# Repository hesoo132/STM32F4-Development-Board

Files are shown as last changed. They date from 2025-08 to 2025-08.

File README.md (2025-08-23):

## 📑 Table of Contents
1. [Power](#1-power-전원부)  
2. [Pin Port](#2-pin-port-핀-포트)  
3. [USB](#3-usb)  
4. [Crystal](#4-crystal-크리스탈-오실레이터)  
5. [MCU](#5-mcu-마이크로컨트롤러-유닛)  
6. [Conclusion](#6-결론)  

---

## 1. Power
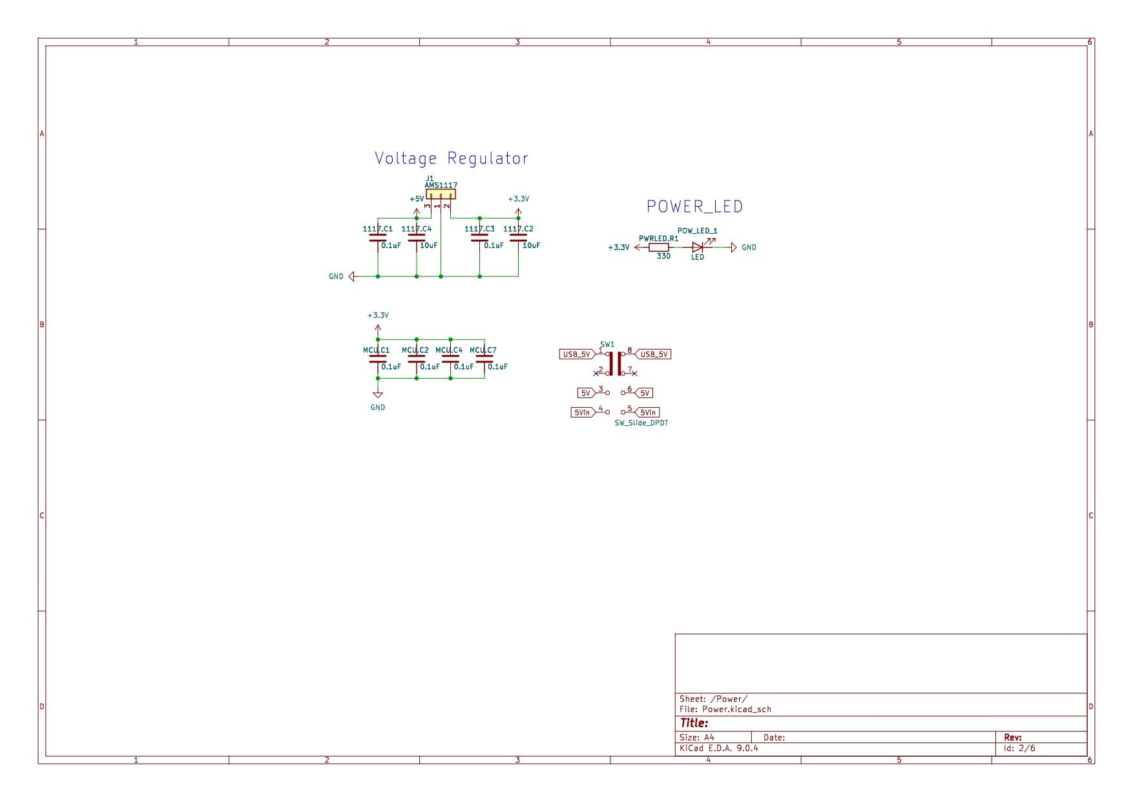
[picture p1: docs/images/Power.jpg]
Power Schematic


- **Function**: Converts external 5V input into a regulated 3.3V supply for the MCU and peripherals.  
- **Components**:  
  - AMS1117 regulator (J1)  
  - Power LED (POW_LED_1) with resistor (330Ω)  
  - Slide switch (SW_Slide_DPDT, SW1) for power control  
  - Decoupling capacitors (0.1µF, 10µF) for stability  

---

## 2. Pin Port
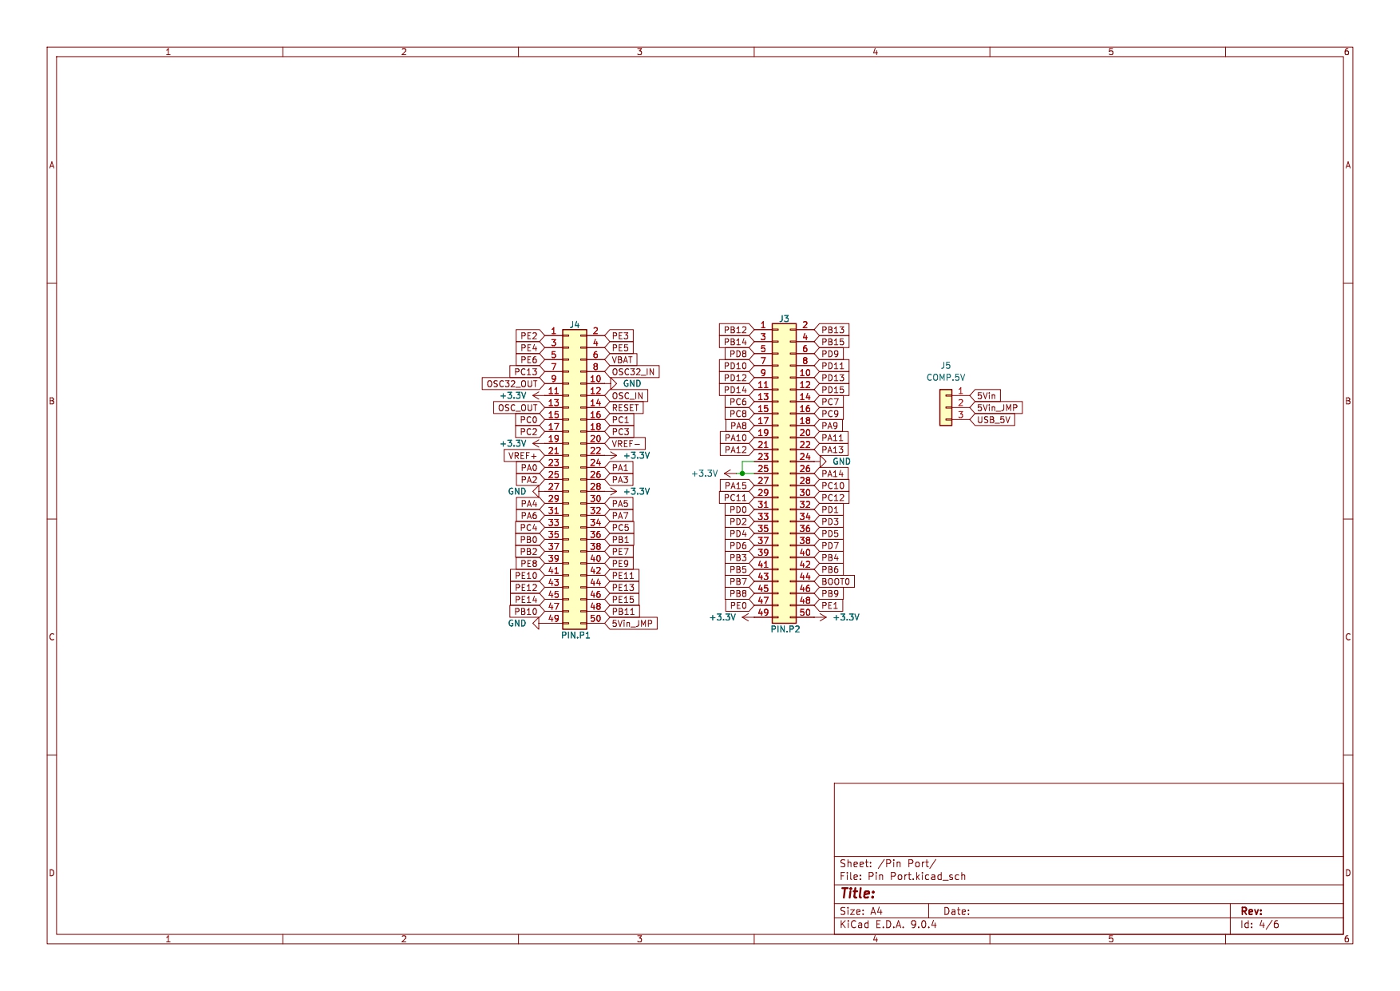
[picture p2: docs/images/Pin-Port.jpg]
Pin Port Schematic


- **Function**: Exposes STM32F407VETx GPIOs through external connectors (J3, J4, J5).  
- **Available Pins**:  
  - GPIO groups: PA, PB, PC, PD, PE  
  - Clock pins: OSC_IN, OSC_OUT, OSC32_IN, OSC32_OUT  
  - Reset and Boot pins  
- **Purpose**: Enables flexible interfacing with sensors, actuators, or other controllers.  

---

## 3. USB
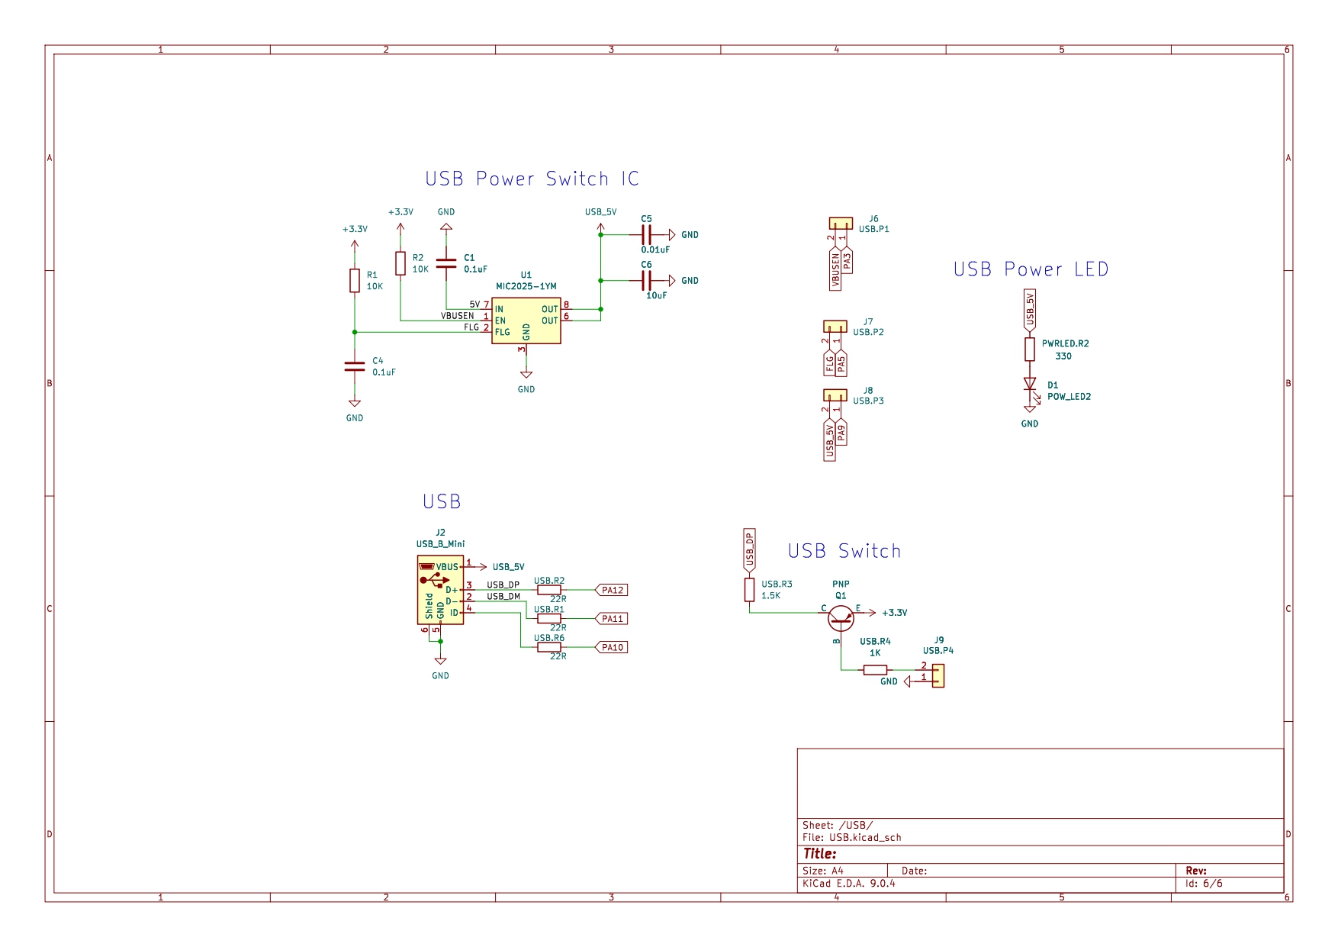
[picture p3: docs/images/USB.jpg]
USB Schematic


- **Function**: Provides USB communication via a Mini-B connector (J2).  
- **Components**:  
  - MIC2025-1YM USB power switch (U1)  
  - Data lines: USB_DP, USB_DM  
  - Protection & series resistors (22Ω)  
  - Power LED (POW_LED2)  
- **Notes**: Supports regulated USB 5V input, current limiting, and device connectivity.  

---

## 4. Crystal
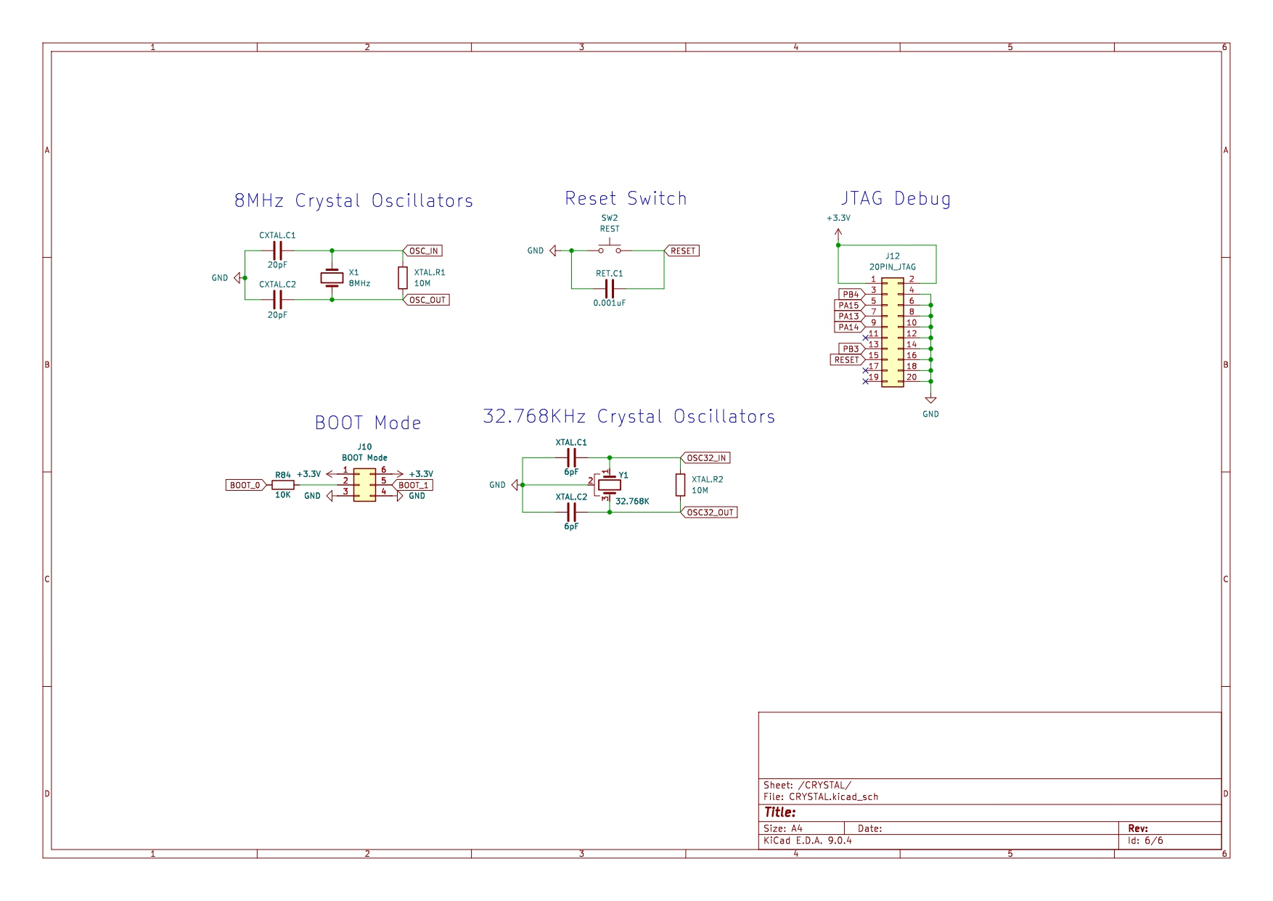
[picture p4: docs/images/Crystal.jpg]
Crystal Schematic


- **Function**: Provides accurate clock sources for the MCU.  
- **Components**:  
  - 8MHz main oscillator (X1) with load capacitors (20pF)  
  - 32.768kHz RTC crystal (Y1) with 6pF capacitors  
  - BOOT Mode selector (J10)  
  - Reset switch (SW2)  
  - 20-pin JTAG/SWD connector (J12) for debugging  

---

## 5. MCU
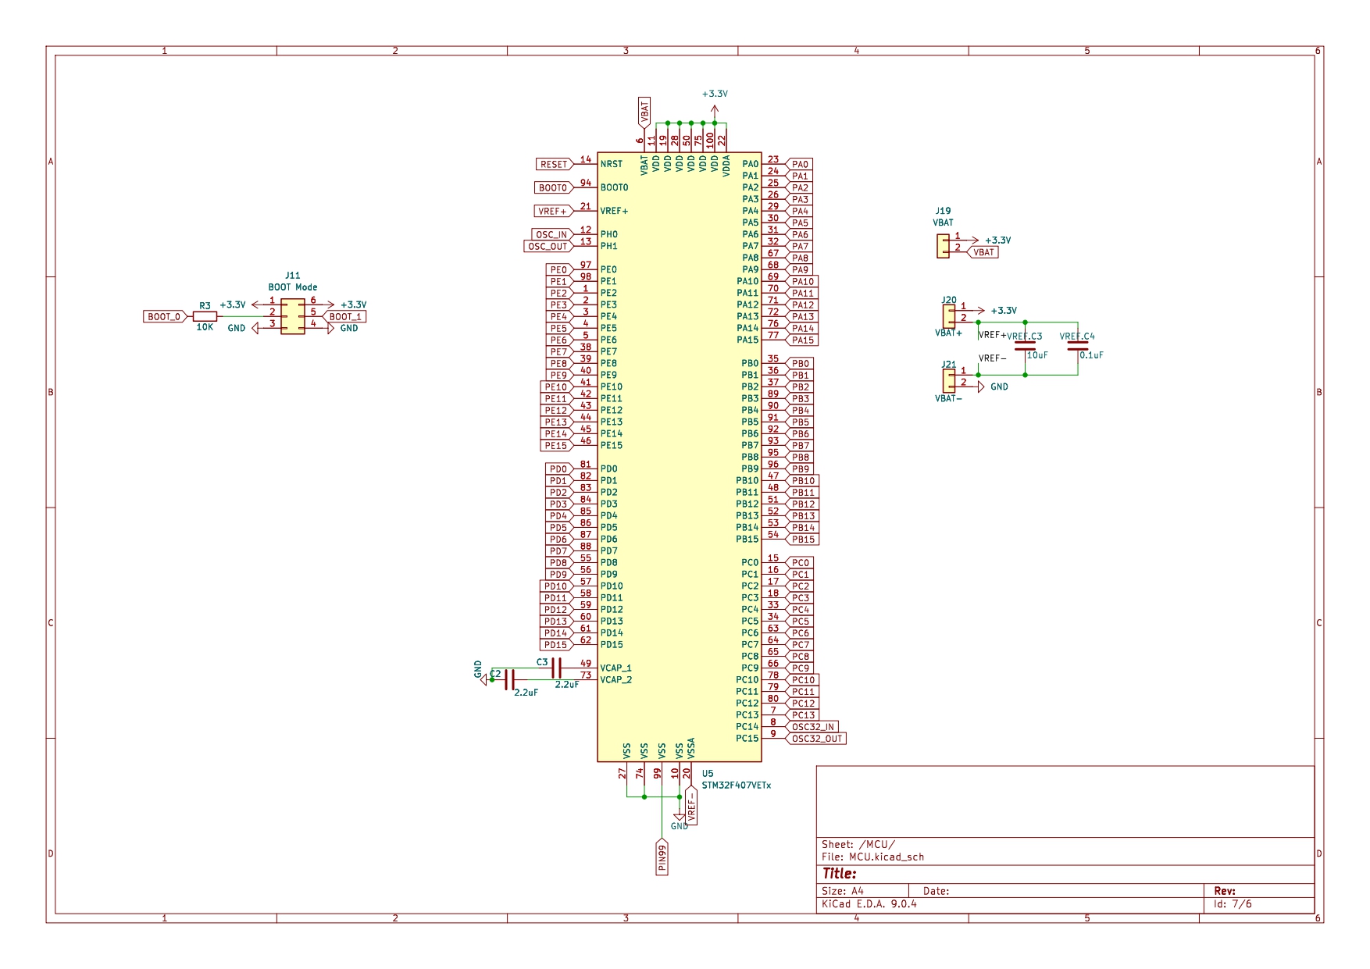
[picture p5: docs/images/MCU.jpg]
MCU Schematic

- **Model**: STM32F407VETx (ARM Cortex-M4)  
- **Function**: Central controller handling all peripherals and system logic.  
- **Connections**:  
  - VCAP capacitors (2.2µF each)  
  - Power pins (3.3V, GND)  
  - BOOT mode jumper (J11)  
  - VBAT connections (J19, J20, J21)  
  - GPIOs (Ports A–E) routed to external headers  
- **Features**:  
  - High-performance MCU core for DSP and control  
  - Rich GPIO set for flexible interfacing  
  - Supports external oscillators and USB  

---

## 6. Conclusion

The **STM32F4Core board** is a versatile core board designed around the STM32F407VETx MCU.  

- **Power Management**: 5V input regulated to 3.3V, with onboard monitoring LEDs and USB power switch.  
- **Expansion**: GPIO-rich design with external pin headers (J3, J4, J5).  
- **USB Support**: Integrated Mini-B port with MIC2025-based power management.  
- **Clock Accuracy**: Dual-crystal design (8MHz + 32.768kHz) ensures reliable MCU timing.  
- **Debugging**: JTAG/SWD interface available for firmware development.  

This makes the board suitable for **embedded system prototyping, robotics, sensor interfacing, and educational use cases** requiring a stable STM32F4 platform.  

---

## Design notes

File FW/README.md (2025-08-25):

# 🔧 STM32F4 Development Board Firmware

## 🔎 Overview
This firmware is designed for the **STM32F407ZET6 Development Board**.  
It provides examples for GPIO, UART, LCD, Timer, PWM, ADC, DAC, I2C and peripheral control.  
The code demonstrates **interrupt-based handling, polling-based logic, and peripheral drivers** using STM32 HAL.

---

## ⚙️ Features

### 1) LED Control
- **B1** → Interrupt-based toggle of LD1  
- **B2** → Polling: Turn ON LEDs  
- **B3** → Polling: Turn OFF LEDs  
- **B4** → Interrupt: Sync LD2 with LD1 (using flag `led_turned_on`)  

👉 Implemented via:
- `HAL_GPIO_EXTI_Callback()` → Handle external interrupts for B1/B4  
- `while(1)` loop polling with `HAL_GPIO_ReadPin()` for B2/B3  

---

### 2) UART – LED Control
- UART1 interrupt receive enabled (`HAL_UART_Receive_IT`)  
- Case 1: Characters `A–C` turn ON LD1, `D–F` turn OFF LD1  
- Case 2: Strings `"LED ON"` and `"LED OFF"` toggle LD2  

👉 Implemented via:
- `HAL_UART_RxCpltCallback()` with buffer and string comparison (`strncmp`)  

---

### 3) UART – LCD Display
- Input characters displayed on **20×4 LCD** via UART interrupt  
- `"Clear"` command clears LCD and resets cursor row  
- Auto line feed with row increment  
- Uses `lcd_Init(4,20), lcd_setCursor(), lcd_string()`  

---

### 4) Timer Control (Reaction Test)
- LD1 (PG13) starts ON, LD2 (PG14) OFF  
- LD1 turns OFF randomly after 1–5 sec (using `rand()`)  
- Then LD2 turns ON randomly after 1–5 sec  
- LCD shows **“R U Ready…?”** and then reaction speed time  
- Button PA0 → Stop timer and freeze reaction time  

👉 Implemented via:
- `HAL_TIM_PeriodElapsedCallback(TIM7)` for random timing  
- `HAL_GPIO_EXTI_Callback()` for stop/resume with button  

---

### 5) Timer Control 2 – Dual LED Toggle
- TIM7 → Toggle LD1 every 1 sec  
- TIM6 → Toggle LD2 every 2 sec  

👉 Implemented via:
- Two base timers with independent callbacks in `HAL_TIM_PeriodElapsedCallback()`  

---

### 6) PWM Control
- **Button 1** → PWM 100Hz  
- **Button 2** → PWM 400Hz  
- **Button 3** → Duty cycle 25%  
- **Button 4** → Duty cycle 75%  

👉 Implemented via:
- TIM2 PWM configuration, updating `PSC`, `ARR`, `CCR1`  
- Flags set by EXTI interrupts (B1–B4)  

---

### 7) PWM Applications
- **SG90 Servo Motor (TIM4_CH2)**  
- **Buzzer (TIM3_CH1)** → 500Hz–1kHz tone  
- **DC Motor (TIM2_CH1/CH2)** → Forward/reverse rotation with duty change  

👉 Real-time PWM frequency adjustment via `PSC` or `ARR` update.  

---

### 8) DAC
- **DAC1 (PA4)** outputs analog voltage (0–3.3V, 12-bit)  
- Example: Constant 1.6V, triangle wave, sine wave with TIM7 interrupt  

👉 Implemented via:
- `HAL_DAC_Start()`  
- `HAL_DAC_SetValue()`  

---

### 9) I2C – EEPROM + LCD
- I2C1 used to read/write external EEPROM (0xA0)  
- Write 10 bytes → Read back & display on LCD  
- Must use `I2C_MEMADD_SIZE_16BIT` for addressing  

👉 Implemented via:
- `HAL_I2C_Mem_Write()` and `HAL_I2C_Mem_Read()`  
- Display results with `lcd_setCurStr()`

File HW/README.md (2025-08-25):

# STM32F4Core Hardware Design

## 🔎 Overview
The **STM32F4Core Board** is a custom core platform built on the **STM32F407VETx** MCU.  
It provides stable power regulation, rich GPIO breakouts, USB connectivity, accurate system/RTC clocks, and full JTAG/SWD debug support for embedded development.

---

## 📸 PCB Overview
| Top View | Bottom View |
|---|---|
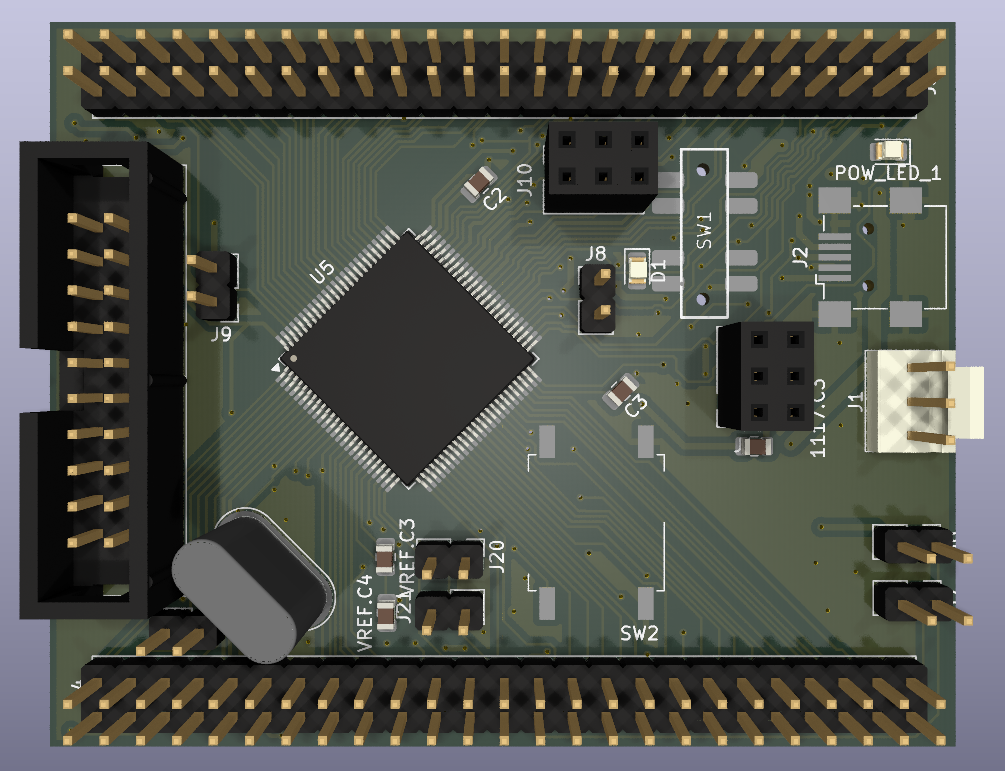
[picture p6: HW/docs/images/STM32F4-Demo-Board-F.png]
Top
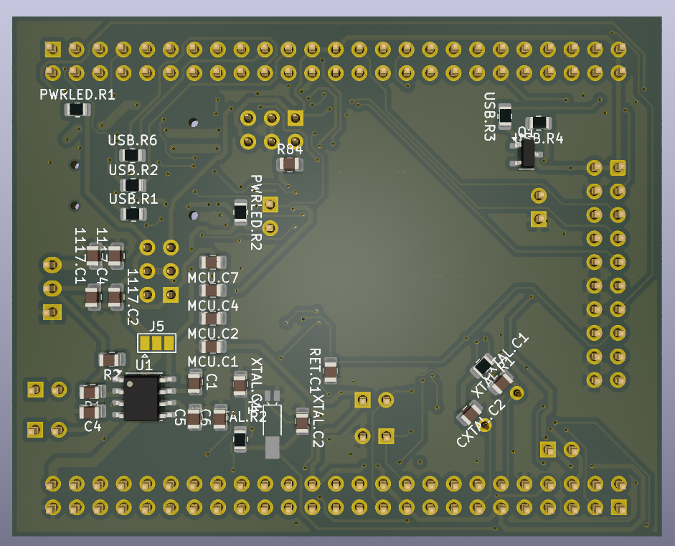
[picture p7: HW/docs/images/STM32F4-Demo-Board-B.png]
Bottom
|  |  |

---

## 📑 Design Resources
- **Schematics**: [STM32F4Core.pdf](STM32F4-Demo-Board.pdf) (6-page schematic for quick view)  
- **EDA Tool**: KiCad (v7)  

---

## 🔧 Key Hardware Notes
- **MCU**: STM32F407VETx (ARM Cortex-M4, 168 MHz, FPU)  
- **Power**: 5 V input → AMS1117 regulator → 3.3 V rail, with on/off slide switch & LED indicator  
- **Clocks**: 8 MHz main crystal + 32.768 kHz RTC crystal  
- **USB**: USB Mini-B connector with **MIC2025-1YM** power switch  
- **GPIO**: PA–PE group pins exposed to headers (J3/J4/J5)  
- **Debug**: 20-pin JTAG header (J12), boot-mode jumper (J11), reset switch (SW2)  

---

## 🧩 Schematic Highlights

### 1) Power
Power  
- **Regulator**: AMS1117 (5 V → 3.3 V)  
- **Indicators**: Power LED (POW_LED_1)  
- **Switch**: Slide switch (SW_Slide_DPDT) for on/off control  

### 2) Pin Ports
Ports  
- **Headers**: J3, J4, J5  
- **Signals**: MCU GPIO (PA/PB/PC/PD/PE), reset, oscillator pins  
- **Use**: Sensor/actuator connections, external module interfacing  

### 3) USB
USB  
- **Connector**: USB Mini-B (J2)  
- **Power Switch**: MIC2025-1YM, with EN/FLG signals to MCU  
- **Signals**: Provides regulated **USB_5V** rail (with current-limit & flag)  
- **Note**: **Power-only design** — no D+/D− data lines connected to MCU. 

### 4) Clocks & Debug
Clocks  
- **Crystals**: 8 MHz (system), 32.768 kHz (RTC)  
- **Reset**: Push switch (SW2)  
- **Debug**: 20-pin JTAG header (J12)  

### 5) MCU
MCU  
- **Chip**: STM32F407VETx  
- **Support**: VCAP capacitors, bypass network, boot-mode jumper (J11)  
- **Role**: Main controller for application logic & peripherals  

---

## ✅ Progress
- [x] Schematics completed (6 pages)  
- [x] PCB prototype fabricated (Rev. A)  
- [x] Power rails validated (5 V → 3.3 V)  
- [x] JTAG/SWD debug verified   
- [x] Full GPIO validation in progress

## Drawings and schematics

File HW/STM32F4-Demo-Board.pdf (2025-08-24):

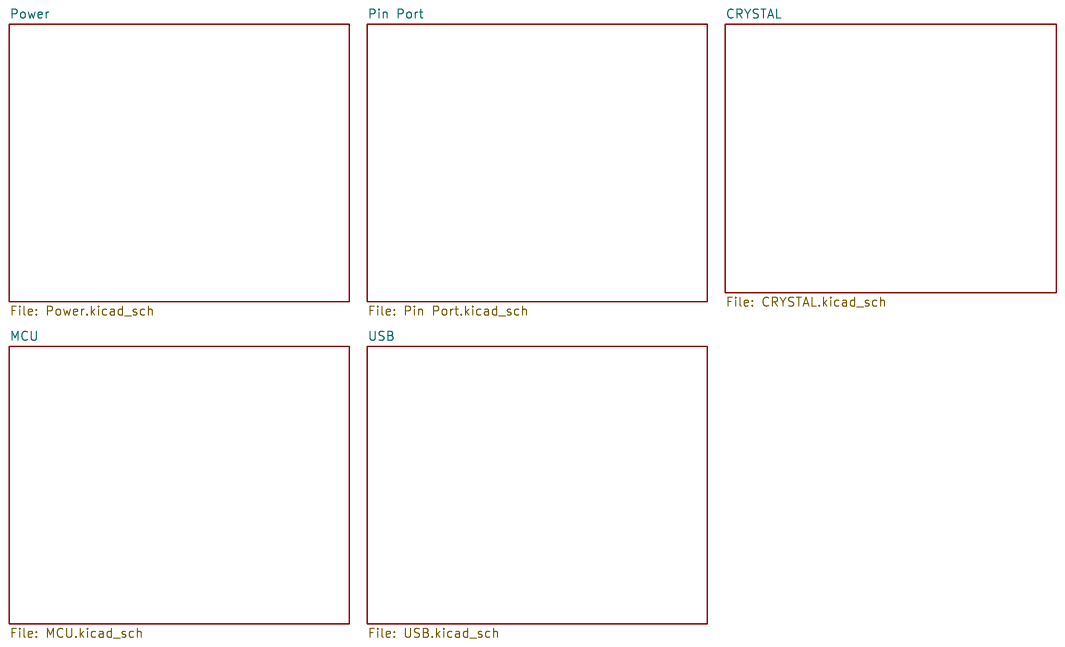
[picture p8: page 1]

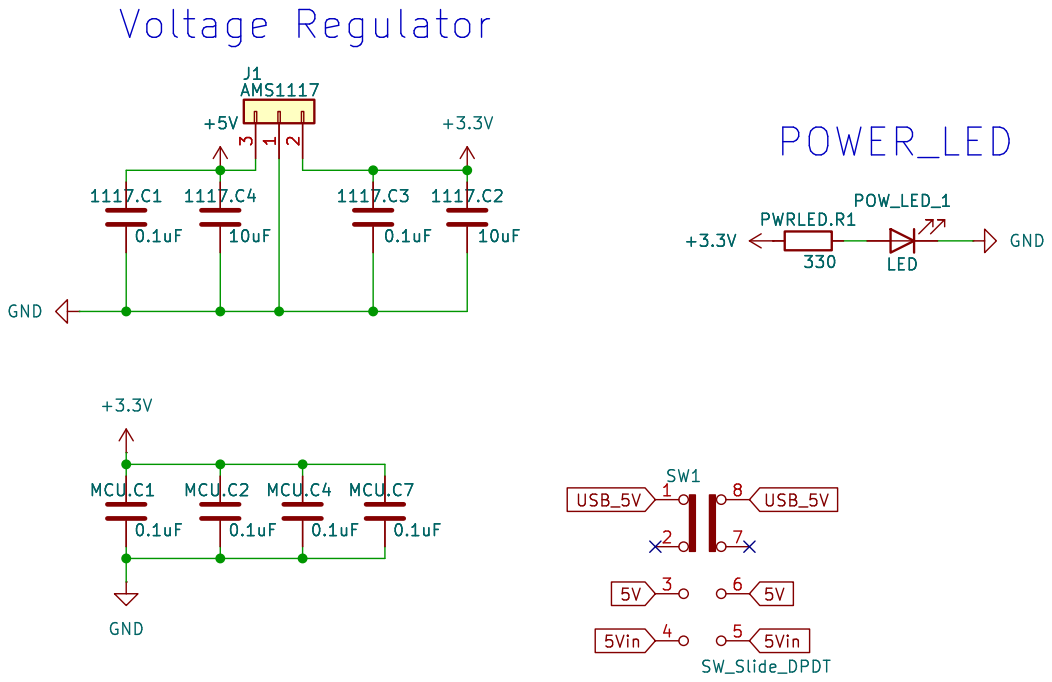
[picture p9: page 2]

Id: 2/6 Title: File: Power.kicad_sch Sheet: /Power/

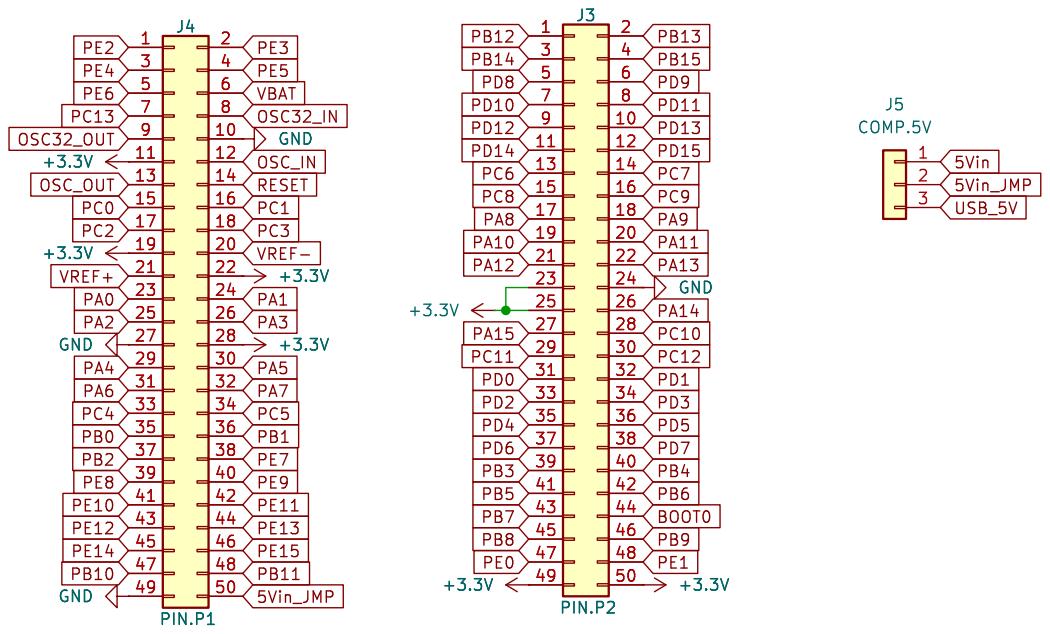
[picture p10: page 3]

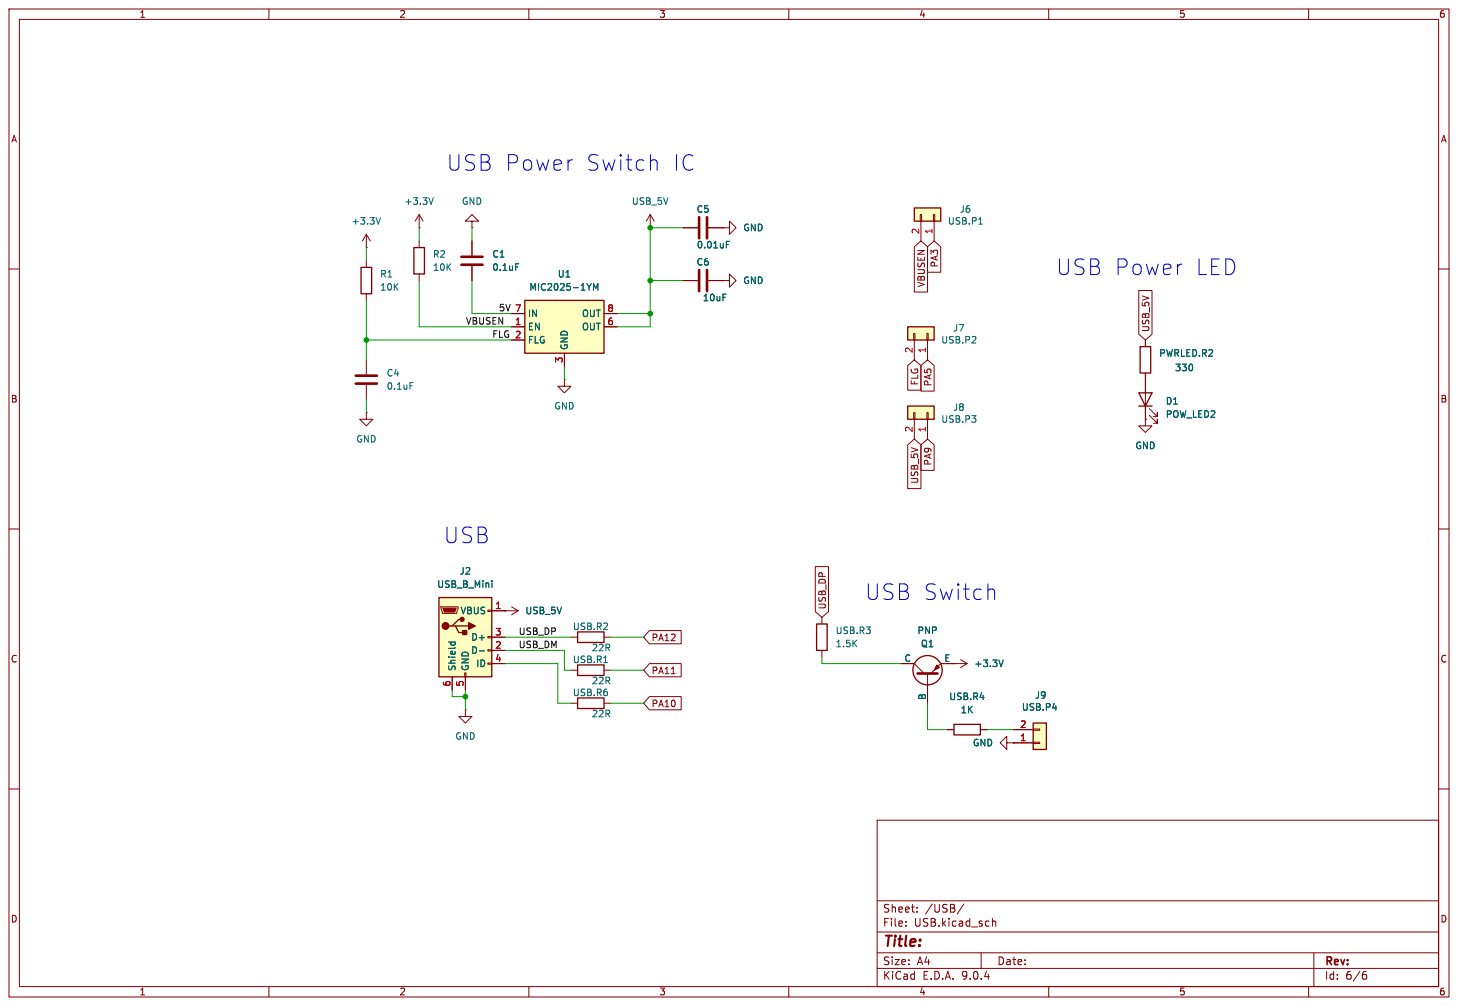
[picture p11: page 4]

Id: 6/6 Title: File: USB.kicad_sch Sheet: /USB/ USB.R3

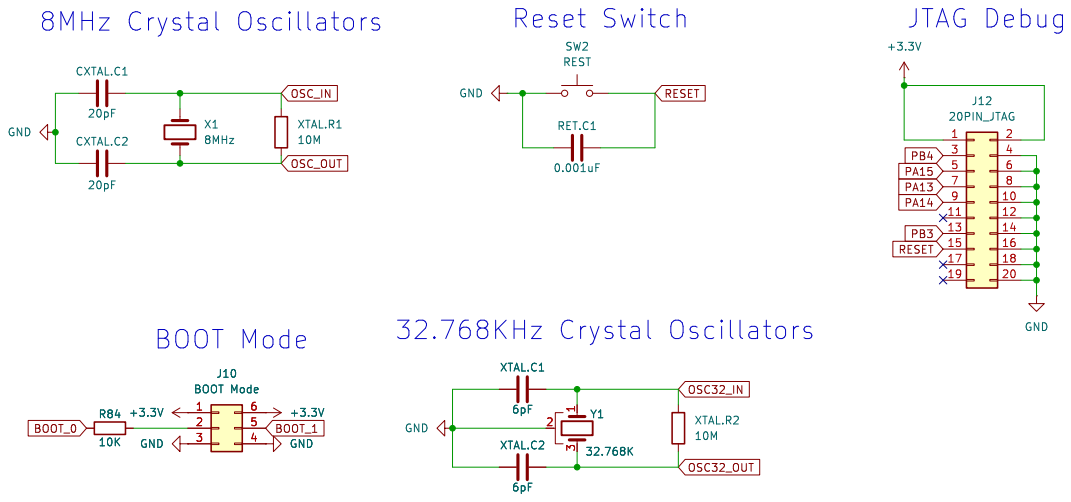
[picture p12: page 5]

Id: 6/6 Title: File: CRYSTAL.kicad_sch Sheet: /CRYSTAL/

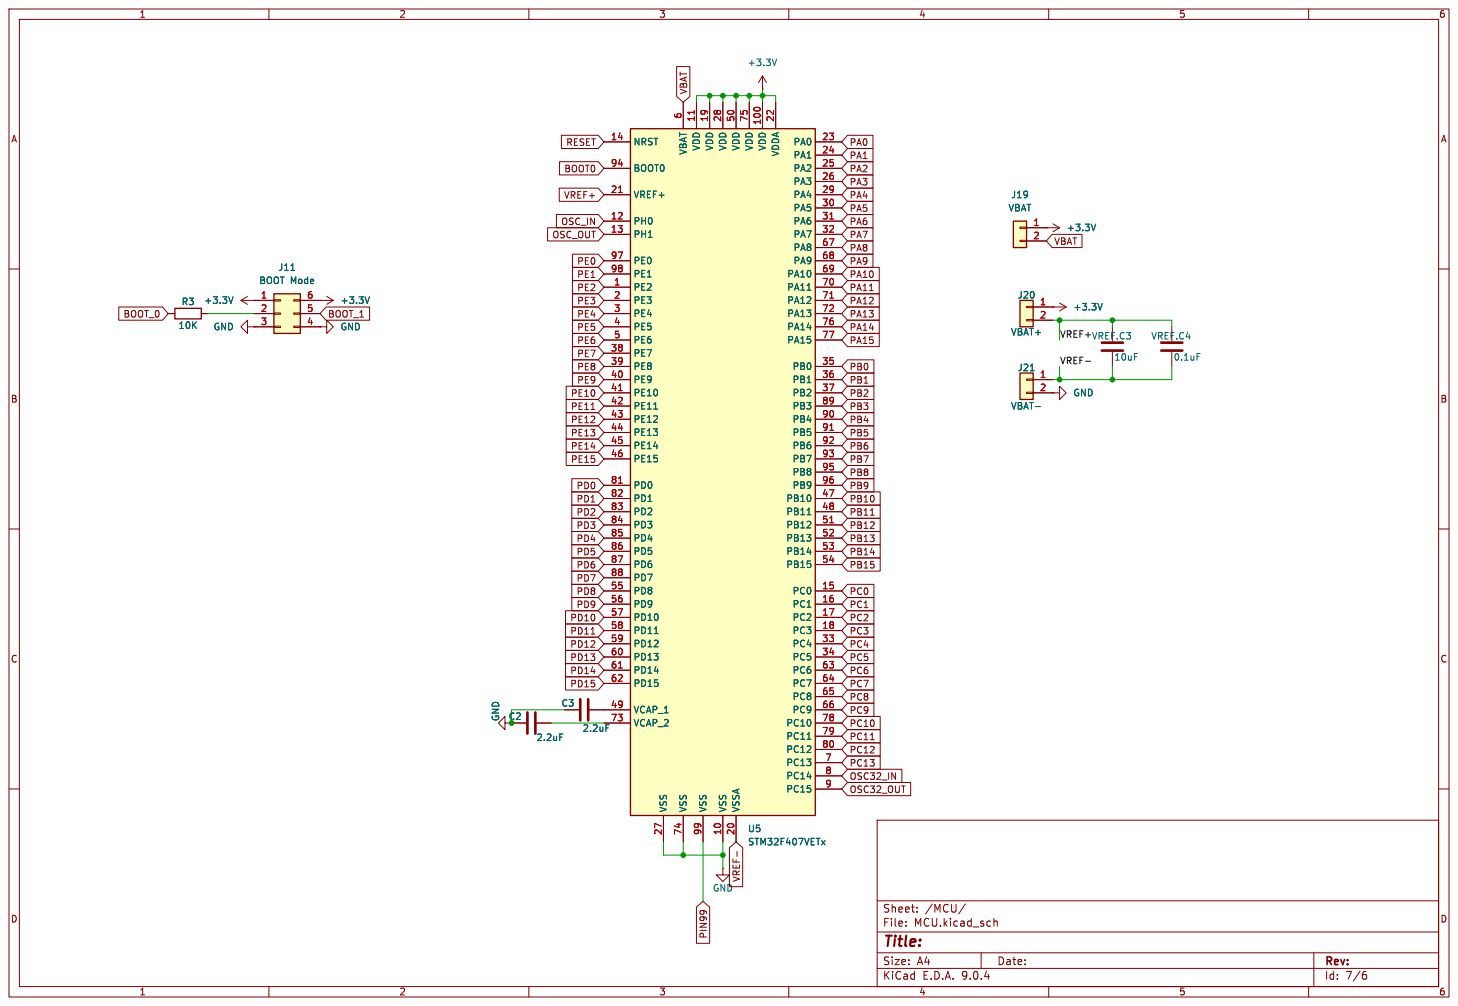
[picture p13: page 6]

Id: 7/6 Title: File: MCU.kicad_sch Sheet: /MCU/

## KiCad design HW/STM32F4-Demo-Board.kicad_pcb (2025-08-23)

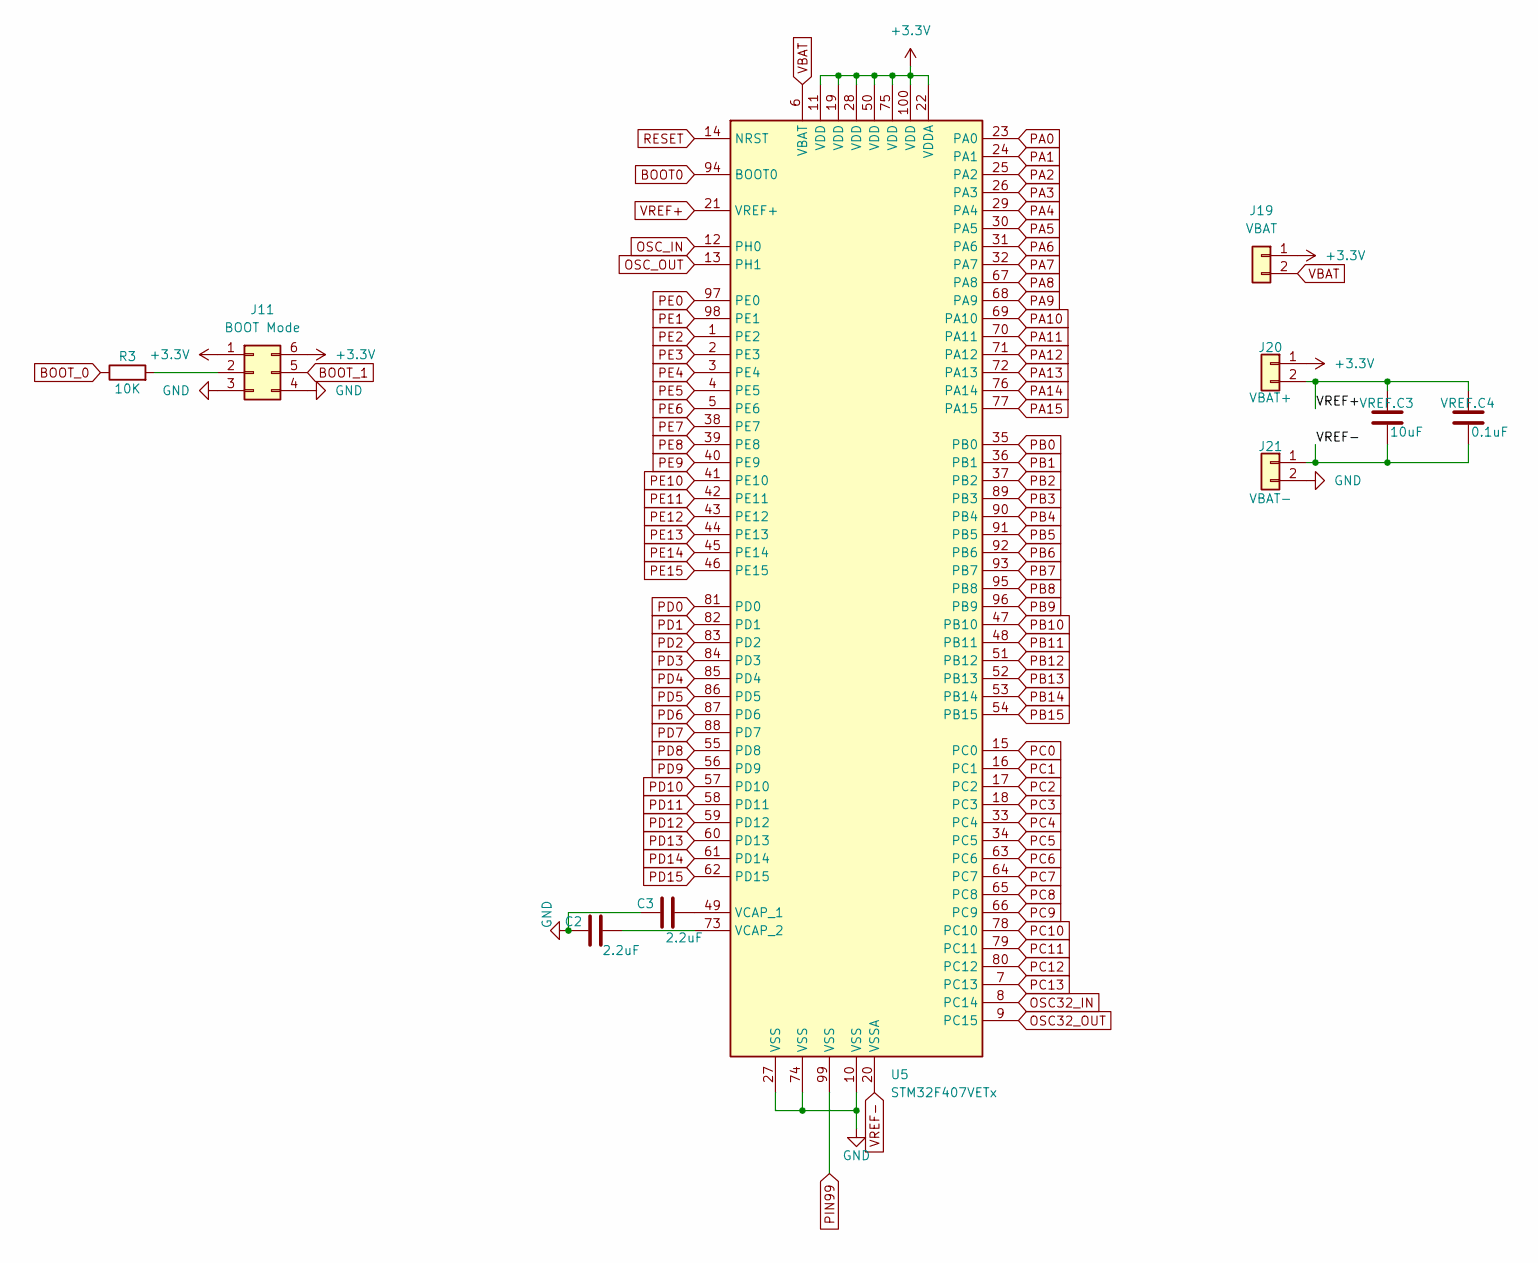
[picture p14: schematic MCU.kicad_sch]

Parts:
C2, C3: 2.2uF; C_0805_2012Metric
J11: BOOT Mode; PinSocket_2x03_P2.54mm_Vertical
J19: VBAT; PinHeader_1x02_P2.54mm_Vertical
J20: VBAT+; PinHeader_1x02_P2.54mm_Vertical
J21: VBAT-; PinHeader_1x02_P2.54mm_Vertical
R3: 10K; C_0805_2012Metric
U5: STM32F407VETx; LQFP-100_14x14mm_P0.5mm
VREF.C3: 10uF; C_0805_2012Metric
VREF.C4: 0.1uF; C_0805_2012Metric

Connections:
+3.3V: J11.1, J11.6, J19.1, J20.1, U5.11 (VDD), U5.19 (VDD), U5.22 (VDDA), U5.28 (VDD), U5.50 (VDD), U5.75 (VDD), U5.100 (VDD); also elsewhere on the board
BOOT0: U5.94 (BOOT0); also elsewhere on the board
BOOT_0: R3.1; also elsewhere on the board
BOOT_1: J11.5; also elsewhere on the board
GND: C2.1, C3.1, J11.3, J11.4, J21.2, U5.10 (VSS), U5.27 (VSS), U5.74 (VSS); also elsewhere on the board
unnamed: J11.2, R3.2
unnamed: C3.2, U5.49 (VCAP_1)
unnamed: C2.2, U5.73 (VCAP_2)
OSC32_IN: U5.8 (PC14); also elsewhere on the board
OSC32_OUT: U5.9 (PC15); also elsewhere on the board
OSC_IN: U5.12 (PH0); also elsewhere on the board
OSC_OUT: U5.13 (PH1); also elsewhere on the board
PA0: U5.23 (PA0); also elsewhere on the board
PA1: U5.24 (PA1); also elsewhere on the board
PA2: U5.25 (PA2); also elsewhere on the board
PA3: U5.26 (PA3); also elsewhere on the board
PA4: U5.29 (PA4); also elsewhere on the board
PA5: U5.30 (PA5); also elsewhere on the board
PA6: U5.31 (PA6); also elsewhere on the board
PA7: U5.32 (PA7); also elsewhere on the board
PA8: U5.67 (PA8); also elsewhere on the board
PA9: U5.68 (PA9); also elsewhere on the board
PA10: U5.69 (PA10); also elsewhere on the board
PA11: U5.70 (PA11); also elsewhere on the board
PA12: U5.71 (PA12); also elsewhere on the board
PA13: U5.72 (PA13); also elsewhere on the board
PA14: U5.76 (PA14); also elsewhere on the board
PA15: U5.77 (PA15); also elsewhere on the board
PB0: U5.35 (PB0); also elsewhere on the board
PB1: U5.36 (PB1); also elsewhere on the board
PB2: U5.37 (PB2); also elsewhere on the board
PB3: U5.89 (PB3); also elsewhere on the board
PB4: U5.90 (PB4); also elsewhere on the board
PB5: U5.91 (PB5); also elsewhere on the board
PB6: U5.92 (PB6); also elsewhere on the board
PB7: U5.93 (PB7); also elsewhere on the board
PB8: U5.95 (PB8); also elsewhere on the board
PB9: U5.96 (PB9); also elsewhere on the board
PB10: U5.47 (PB10); also elsewhere on the board
PB11: U5.48 (PB11); also elsewhere on the board
PB12: U5.51 (PB12); also elsewhere on the board
PB13: U5.52 (PB13); also elsewhere on the board
PB14: U5.53 (PB14); also elsewhere on the board
PB15: U5.54 (PB15); also elsewhere on the board
PC0: U5.15 (PC0); also elsewhere on the board
PC1: U5.16 (PC1); also elsewhere on the board
PC2: U5.17 (PC2); also elsewhere on the board
PC3: U5.18 (PC3); also elsewhere on the board
PC4: U5.33 (PC4); also elsewhere on the board
PC5: U5.34 (PC5); also elsewhere on the board
PC6: U5.63 (PC6); also elsewhere on the board
PC7: U5.64 (PC7); also elsewhere on the board
PC8: U5.65 (PC8); also elsewhere on the board
PC9: U5.66 (PC9); also elsewhere on the board
PC10: U5.78 (PC10); also elsewhere on the board
PC11: U5.79 (PC11); also elsewhere on the board
PC12: U5.80 (PC12); also elsewhere on the board
PC13: U5.7 (PC13); also elsewhere on the board
PD0: U5.81 (PD0); also elsewhere on the board
PD1: U5.82 (PD1); also elsewhere on the board
PD2: U5.83 (PD2); also elsewhere on the board
PD3: U5.84 (PD3); also elsewhere on the board
PD4: U5.85 (PD4); also elsewhere on the board
PD5: U5.86 (PD5); also elsewhere on the board
PD6: U5.87 (PD6); also elsewhere on the board
PD7: U5.88 (PD7); also elsewhere on the board
PD8: U5.55 (PD8); also elsewhere on the board
PD9: U5.56 (PD9); also elsewhere on the board
PD10: U5.57 (PD10); also elsewhere on the board
PD11: U5.58 (PD11); also elsewhere on the board
PD12: U5.59 (PD12); also elsewhere on the board
PD13: U5.60 (PD13); also elsewhere on the board
PD14: U5.61 (PD14); also elsewhere on the board
PD15: U5.62 (PD15); also elsewhere on the board
PE0: U5.97 (PE0); also elsewhere on the board
PE1: U5.98 (PE1); also elsewhere on the board
PE2: U5.1 (PE2); also elsewhere on the board
PE3: U5.2 (PE3); also elsewhere on the board
PE4: U5.3 (PE4); also elsewhere on the board
PE5: U5.4 (PE5); also elsewhere on the board
PE6: U5.5 (PE6); also elsewhere on the board
PE7: U5.38 (PE7); also elsewhere on the board
PE8: U5.39 (PE8); also elsewhere on the board
PE9: U5.40 (PE9); also elsewhere on the board
PE10: U5.41 (PE10); also elsewhere on the board
PE11: U5.42 (PE11); also elsewhere on the board
PE12: U5.43 (PE12); also elsewhere on the board
PE13: U5.44 (PE13); also elsewhere on the board
PE14: U5.45 (PE14); also elsewhere on the board
PE15: U5.46 (PE15); also elsewhere on the board
PIN99: U5.99 (VSS)
RESET: U5.14 (NRST); also elsewhere on the board
VBAT: J19.2, U5.6 (VBAT); also elsewhere on the board
VREF+: J20.2, U5.21 (VREF+), VREF.C3.1, VREF.C4.1; also elsewhere on the board
VREF-: J21.1, U5.20 (VSSA), VREF.C3.2, VREF.C4.2; also elsewhere on the board

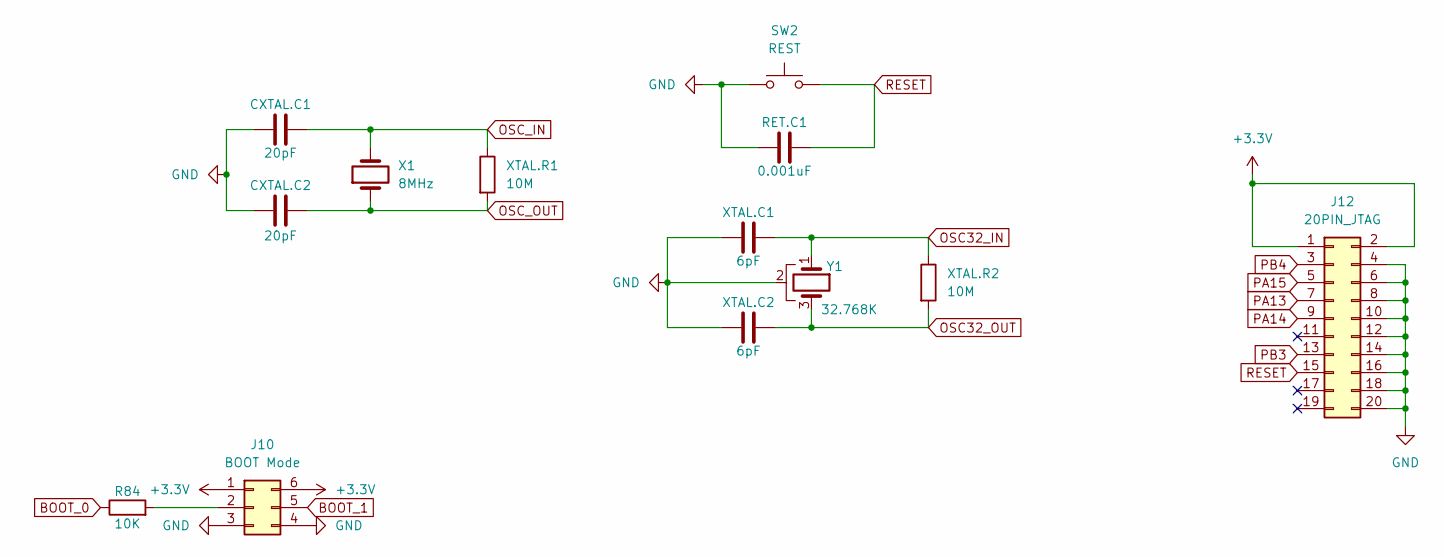
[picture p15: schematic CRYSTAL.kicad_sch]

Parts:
CXTAL.C1, CXTAL.C2: 20pF; C_0805_2012Metric
J10: BOOT Mode; PinSocket_2x03_P2.54mm_Vertical
J12: 20PIN_JTAG; IDC-Header_2x10_P2.54mm_Vertical
R84: 10K; C_0805_2012Metric
RET.C1: 0.001uF; C_0805_2012Metric
SW2: REST; SW_MEC_5GSH9
X1: 8MHz; Crystal_HC18-U_Vertical
XTAL.C1, XTAL.C2: 6pF; C_0805_2012Metric
XTAL.R1, XTAL.R2: 10M; R_0805_2012Metric
Y1: 32.768K; Crystal_SMD_MicroCrystal_MS3V-T1R

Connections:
+3.3V: J10.1, J10.6, J12.1, J12.2; also elsewhere on the board
BOOT_0: R84.1; also elsewhere on the board
BOOT_1: J10.5; also elsewhere on the board
GND: CXTAL.C1.1, CXTAL.C2.1, J10.3, J10.4, J12.4, J12.6, J12.8, J12.10, J12.12, J12.14, J12.16, J12.18, J12.20, RET.C1.1, SW2.1 (A), SW2.2 (A), XTAL.C1.1, XTAL.C2.1, Y1.2; also elsewhere on the board
unnamed: J10.2, R84.2
OSC32_IN: XTAL.C1.2, XTAL.R2.1, Y1.1; also elsewhere on the board
OSC32_OUT: XTAL.C2.2, XTAL.R2.2, Y1.3; also elsewhere on the board
OSC_IN: CXTAL.C1.2, X1.2, XTAL.R1.1; also elsewhere on the board
OSC_OUT: CXTAL.C2.2, X1.1, XTAL.R1.2; also elsewhere on the board
PA13: J12.7; also elsewhere on the board
PA14: J12.9; also elsewhere on the board
PA15: J12.5; also elsewhere on the board
PB3: J12.13; also elsewhere on the board
PB4: J12.3; also elsewhere on the board
RESET: J12.15, RET.C1.2, SW2.3 (B), SW2.4 (B); also elsewhere on the board

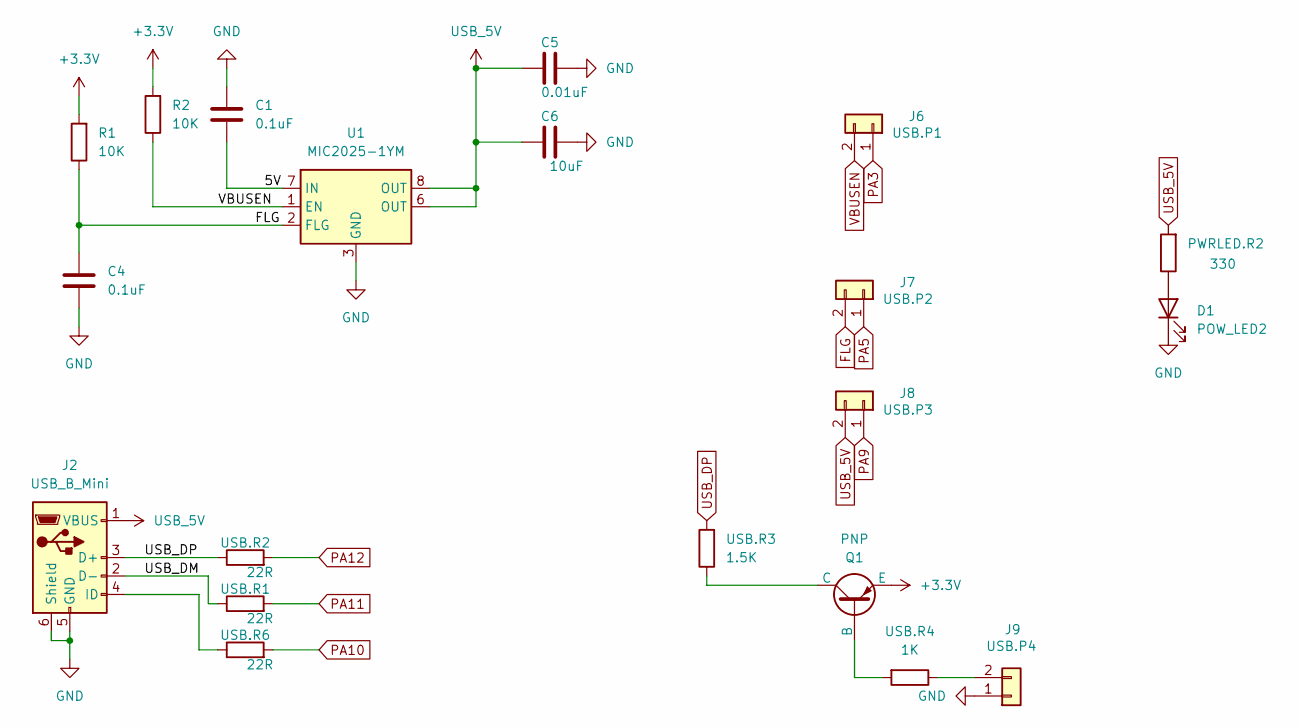
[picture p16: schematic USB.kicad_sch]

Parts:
C1, C4: 0.1uF; C_0805_2012Metric
C5: 0.01uF; C_0805_2012Metric
C6: 10uF; C_0805_2012Metric
D1: POW_LED2; LED_0805_2012Metric
J2: USB_B_Mini; USB_Mini-B_Wuerth_65100516121_Horizontal
J6: USB.P1; PinHeader_1x02_P2.54mm_Vertical
J7: USB.P2; PinHeader_1x02_P2.54mm_Vertical
J8: USB.P3; PinHeader_1x02_P2.54mm_Vertical
J9: USB.P4; PinHeader_1x02_P2.54mm_Vertical
PWRLED.R2: 330; R_0805_2012Metric
Q1: PNP; SOT-23-3
R1, R2: 10K; C_0805_2012Metric
U1: MIC2025-1YM; SOIC-8_3.9x4.9mm_P1.27mm
USB.R1, USB.R2, USB.R6: 22R; R_0805_2012Metric
USB.R3: 1.5K; R_0805_2012Metric
USB.R4: 1K; R_0805_2012Metric

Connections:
+3.3V: Q1.3 (E), R1.2, R2.2; also elsewhere on the board
/USB/5V: C1.2, U1.7 (IN)
/USB/USB_DM: J2.2 (D-), USB.R1.1
FLG: C4.1, J7.2, R1.1, U1.2 (FLG)
GND: C1.1, C4.2, C5.2, C6.2, D1.1 (K), J2.5 (GND), J2.6 (Shield), J9.1, U1.3 (GND); also elsewhere on the board
unnamed: D1.2 (A), PWRLED.R2.1
unnamed: J2.4 (ID), USB.R6.1
unnamed: J9.2, USB.R4.1
unnamed: Q1.2 (B), USB.R4.2
unnamed: Q1.1 (C), USB.R3.1
PA3: J6.1; also elsewhere on the board
PA5: J7.1; also elsewhere on the board
PA9: J8.1; also elsewhere on the board
PA10: USB.R6.2; also elsewhere on the board
PA11: USB.R1.2; also elsewhere on the board
PA12: USB.R2.2; also elsewhere on the board
USB_5V: C5.1, C6.1, J2.1 (VBUS), J8.2, PWRLED.R2.2, U1.6 (OUT), U1.8 (OUT); also elsewhere on the board
USB_DP: J2.3 (D+), USB.R2.1, USB.R3.2
VBUSEN: J6.2, R2.1, U1.1 (EN)

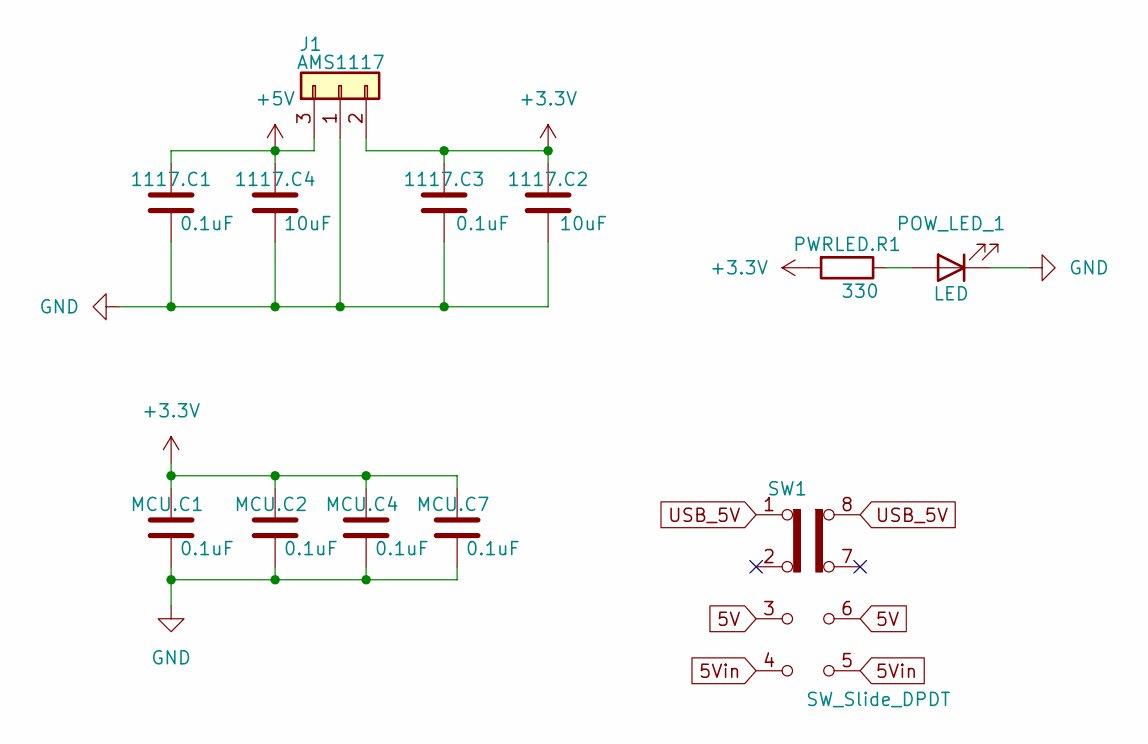
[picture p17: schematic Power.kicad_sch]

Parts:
1117.C1, 1117.C3: 0.1uF; C_0805_2012Metric
1117.C2, 1117.C4: 10uF; C_0805_2012Metric
J1: AMS1117; FanPinHeader_1x03_P2.54mm_Vertical
MCU.C1, MCU.C2, MCU.C4, MCU.C7: 0.1uF; C_0805_2012Metric
POW_LED_1: LED; LED_0805_2012Metric
PWRLED.R1: 330; R_0805_2012Metric
SW1: SW_Slide_DPDT; MY_SW

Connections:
5V: SW1.3 (C), SW1.6 (A)
5Vin: SW1.4, SW1.5; also elsewhere on the board
+3.3V: 1117.C2.1, 1117.C3.1, J1.2, MCU.C1.1, MCU.C2.1, MCU.C4.1, MCU.C7.1, PWRLED.R1.2; also elsewhere on the board
+5V: 1117.C1.1, 1117.C4.1, J1.3
GND: 1117.C1.2, 1117.C2.2, 1117.C3.2, 1117.C4.2, J1.1, MCU.C1.2, MCU.C2.2, MCU.C4.2, MCU.C7.2, POW_LED_1.1 (K); also elsewhere on the board
unnamed: POW_LED_1.2 (A), PWRLED.R1.1
USB_5V: SW1.1 (A), SW1.8 (C); also elsewhere on the board

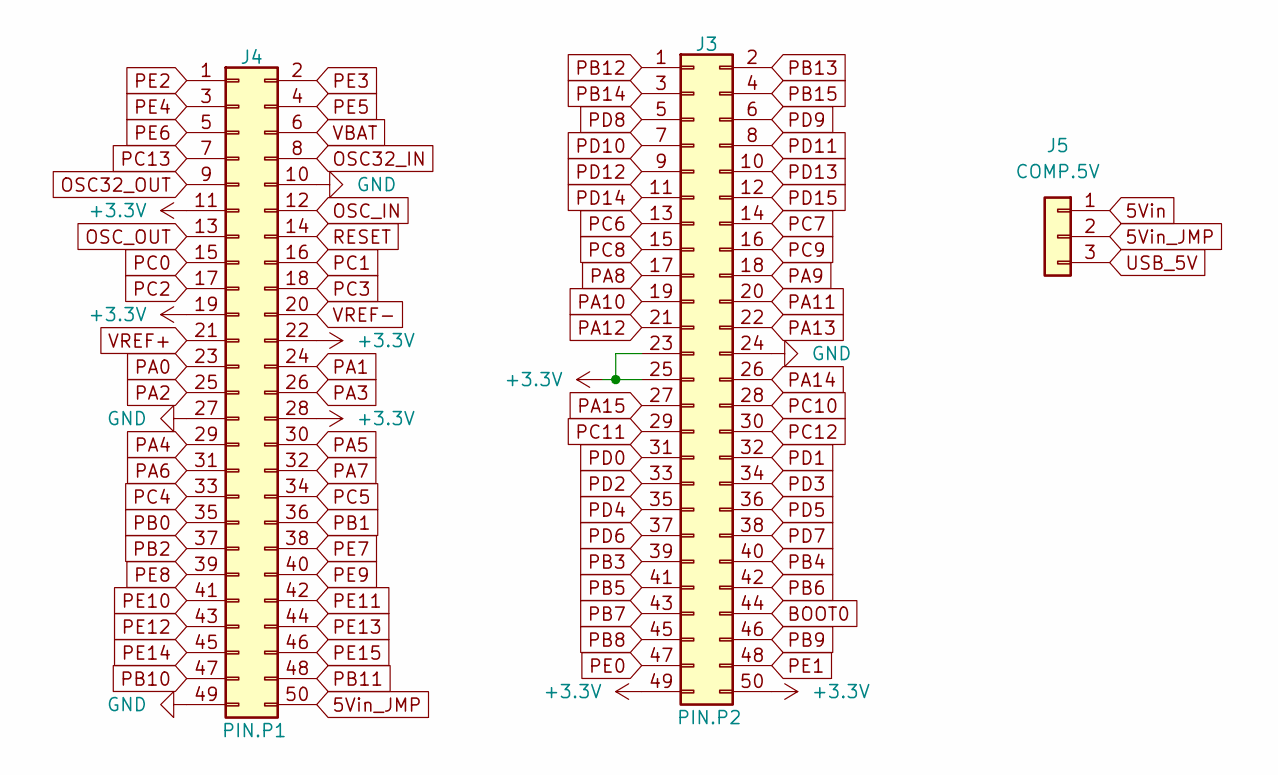
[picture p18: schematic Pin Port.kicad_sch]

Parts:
J3: PIN.P2; PinHeader_2x25_P2.54mm_Vertical
J4: PIN.P1; PinHeader_2x25_P2.54mm_Vertical
J5: COMP.5V; SolderJumper-3_P1.3mm_Open_Pad1.0x1.5mm

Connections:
5Vin: J5.1; also elsewhere on the board
5Vin_JMP: J4.50, J5.2
+3.3V: J3.23, J3.25, J3.49, J3.50, J4.11, J4.19, J4.22, J4.28; also elsewhere on the board
BOOT0: J3.44; also elsewhere on the board
GND: J3.24, J4.10, J4.27, J4.49; also elsewhere on the board
OSC32_IN: J4.8; also elsewhere on the board
OSC32_OUT: J4.9; also elsewhere on the board
OSC_IN: J4.12; also elsewhere on the board
OSC_OUT: J4.13; also elsewhere on the board
PA0: J4.23; also elsewhere on the board
PA1: J4.24; also elsewhere on the board
PA2: J4.25; also elsewhere on the board
PA3: J4.26; also elsewhere on the board
PA4: J4.29; also elsewhere on the board
PA5: J4.30; also elsewhere on the board
PA6: J4.31; also elsewhere on the board
PA7: J4.32; also elsewhere on the board
PA8: J3.17; also elsewhere on the board
PA9: J3.18; also elsewhere on the board
PA10: J3.19; also elsewhere on the board
PA11: J3.20; also elsewhere on the board
PA12: J3.21; also elsewhere on the board
PA13: J3.22; also elsewhere on the board
PA14: J3.26; also elsewhere on the board
PA15: J3.27; also elsewhere on the board
PB0: J4.35; also elsewhere on the board
PB1: J4.36; also elsewhere on the board
PB2: J4.37; also elsewhere on the board
PB3: J3.39; also elsewhere on the board
PB4: J3.40; also elsewhere on the board
PB5: J3.41; also elsewhere on the board
PB6: J3.42; also elsewhere on the board
PB7: J3.43; also elsewhere on the board
PB8: J3.45; also elsewhere on the board
PB9: J3.46; also elsewhere on the board
PB10: J4.47; also elsewhere on the board
PB11: J4.48; also elsewhere on the board
PB12: J3.1; also elsewhere on the board
PB13: J3.2; also elsewhere on the board
PB14: J3.3; also elsewhere on the board
PB15: J3.4; also elsewhere on the board
PC0: J4.15; also elsewhere on the board
PC1: J4.16; also elsewhere on the board
PC2: J4.17; also elsewhere on the board
PC3: J4.18; also elsewhere on the board
PC4: J4.33; also elsewhere on the board
PC5: J4.34; also elsewhere on the board
PC6: J3.13; also elsewhere on the board
PC7: J3.14; also elsewhere on the board
PC8: J3.15; also elsewhere on the board
PC9: J3.16; also elsewhere on the board
PC10: J3.28; also elsewhere on the board
PC11: J3.29; also elsewhere on the board
PC12: J3.30; also elsewhere on the board
PC13: J4.7; also elsewhere on the board
PD0: J3.31; also elsewhere on the board
PD1: J3.32; also elsewhere on the board
PD2: J3.33; also elsewhere on the board
PD3: J3.34; also elsewhere on the board
PD4: J3.35; also elsewhere on the board
PD5: J3.36; also elsewhere on the board
PD6: J3.37; also elsewhere on the board
PD7: J3.38; also elsewhere on the board
PD8: J3.5; also elsewhere on the board
PD9: J3.6; also elsewhere on the board
PD10: J3.7; also elsewhere on the board
PD11: J3.8; also elsewhere on the board
PD12: J3.9; also elsewhere on the board
PD13: J3.10; also elsewhere on the board
PD14: J3.11; also elsewhere on the board
PD15: J3.12; also elsewhere on the board
PE0: J3.47; also elsewhere on the board
PE1: J3.48; also elsewhere on the board
PE2: J4.1; also elsewhere on the board
PE3: J4.2; also elsewhere on the board
PE4: J4.3; also elsewhere on the board
PE5: J4.4; also elsewhere on the board
PE6: J4.5; also elsewhere on the board
PE7: J4.38; also elsewhere on the board
PE8: J4.39; also elsewhere on the board
PE9: J4.40; also elsewhere on the board
PE10: J4.41; also elsewhere on the board
PE11: J4.42; also elsewhere on the board
PE12: J4.43; also elsewhere on the board
PE13: J4.44; also elsewhere on the board
PE14: J4.45; also elsewhere on the board
PE15: J4.46; also elsewhere on the board
RESET: J4.14; also elsewhere on the board
USB_5V: J5.3; also elsewhere on the board
VBAT: J4.6; also elsewhere on the board
VREF+: J4.21; also elsewhere on the board
VREF-: J4.20; also elsewhere on the board

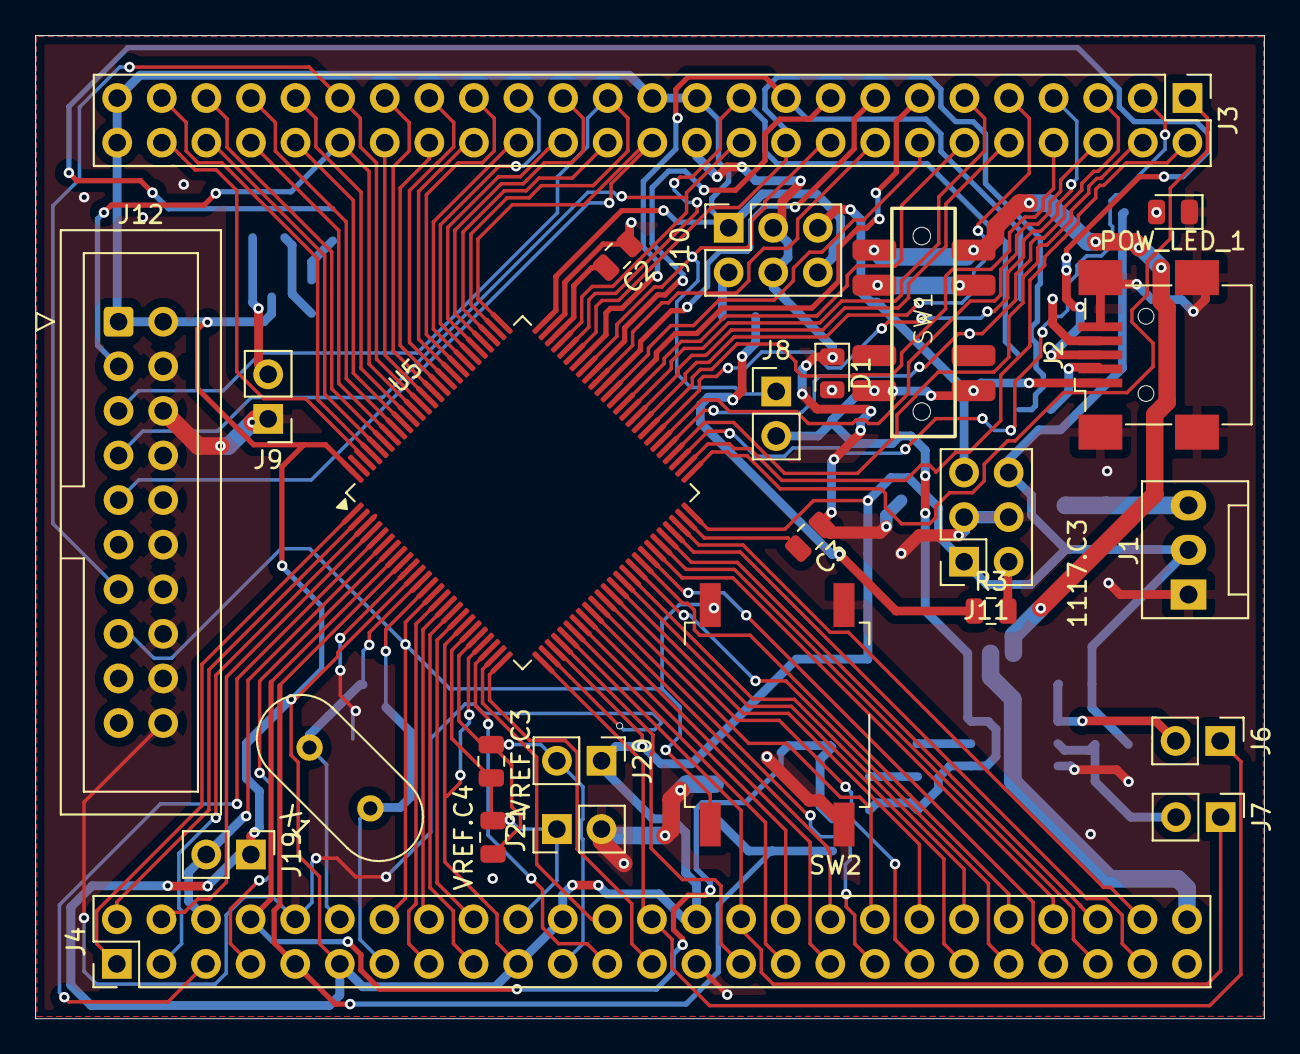
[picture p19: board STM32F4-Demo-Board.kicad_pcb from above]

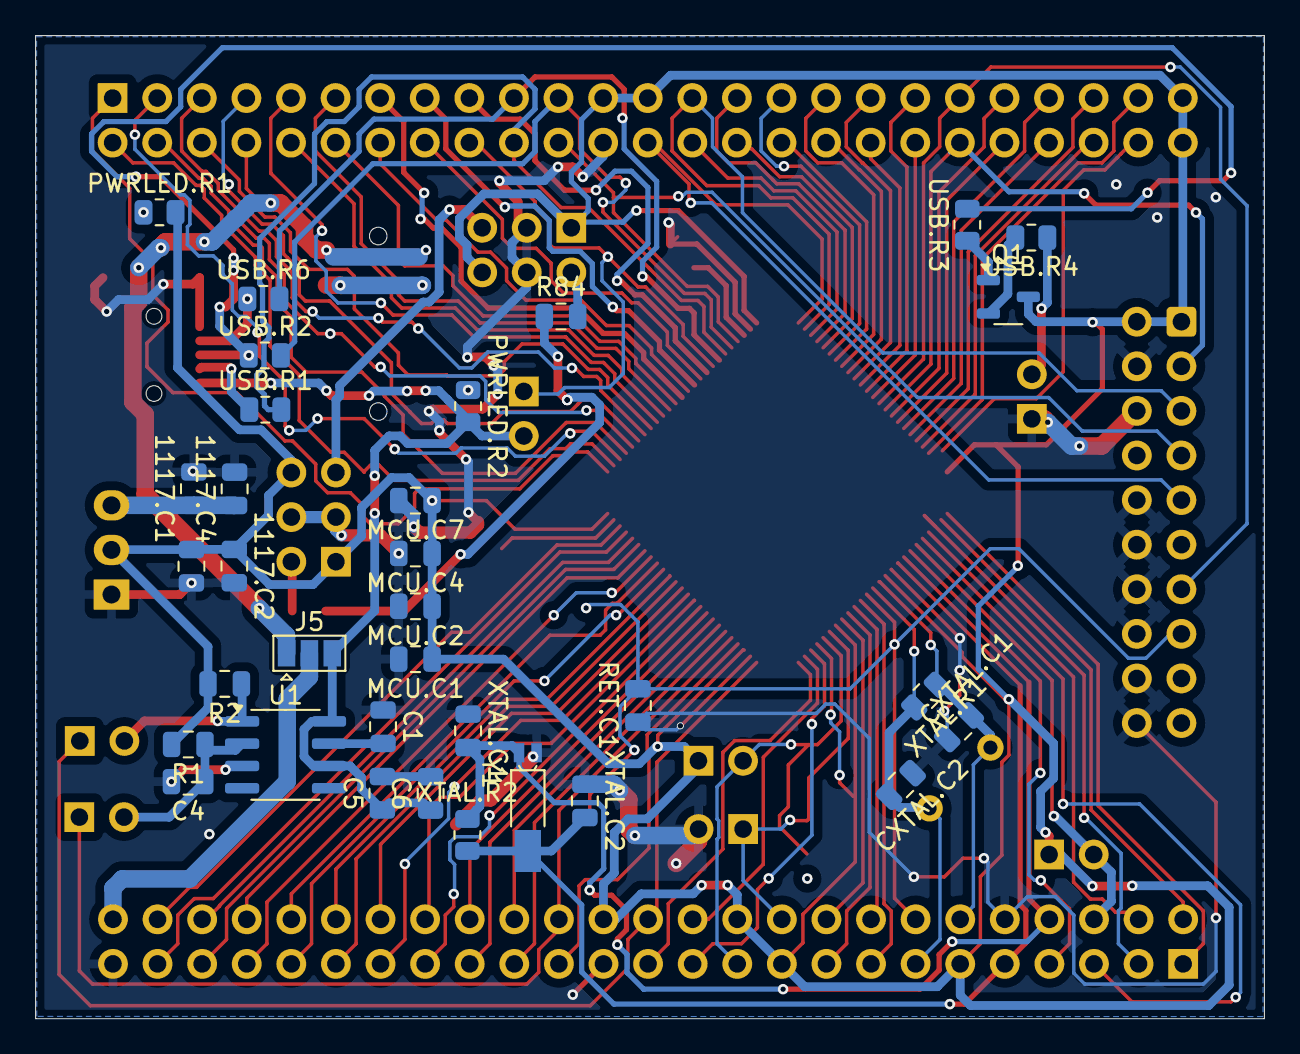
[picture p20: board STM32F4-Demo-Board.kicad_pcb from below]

Board: 2 copper layers, 70.0 x 56.0 mm, 58 parts (33 on the bottom side), 111 nets.
